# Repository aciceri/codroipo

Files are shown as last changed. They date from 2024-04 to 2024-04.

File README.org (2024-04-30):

* Codroipo

~codroipo~ is my personalized [[https://github.com/beekeeb/Allium58][Allium58]].
Basically I simply removed the OLED display and everything related to wired build, sligthly moved some components and added some cosmetics.

** Build the firmware

#+BEGIN_SRC sh
nix build github:aciceri/codroipo#firmware
#+END_SRC

** Flash the firmware

#+BEGIN_SRC sh
nix run github:aciceri/codroipo#flash
#+END_SRC

** Pictures

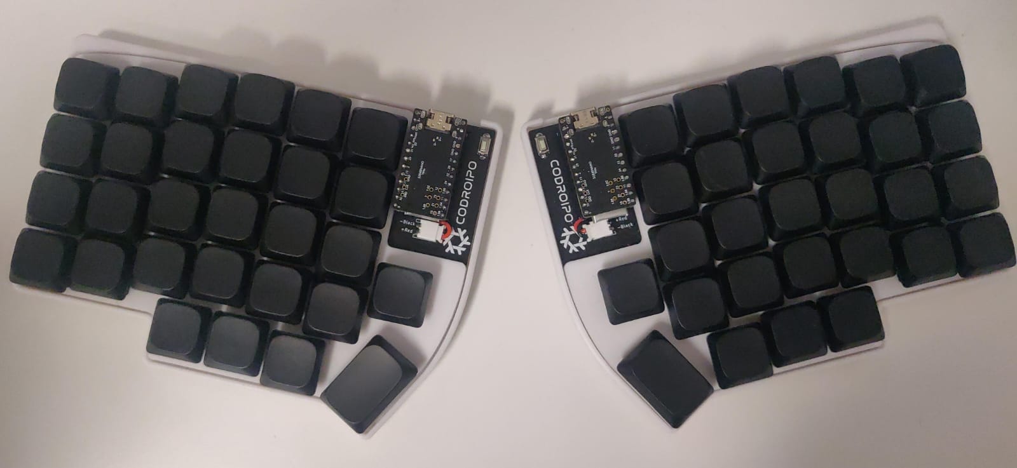
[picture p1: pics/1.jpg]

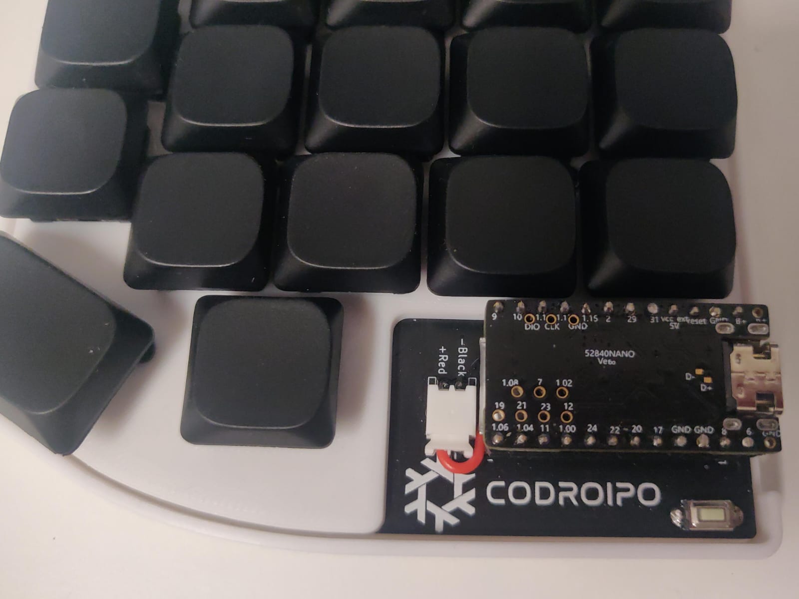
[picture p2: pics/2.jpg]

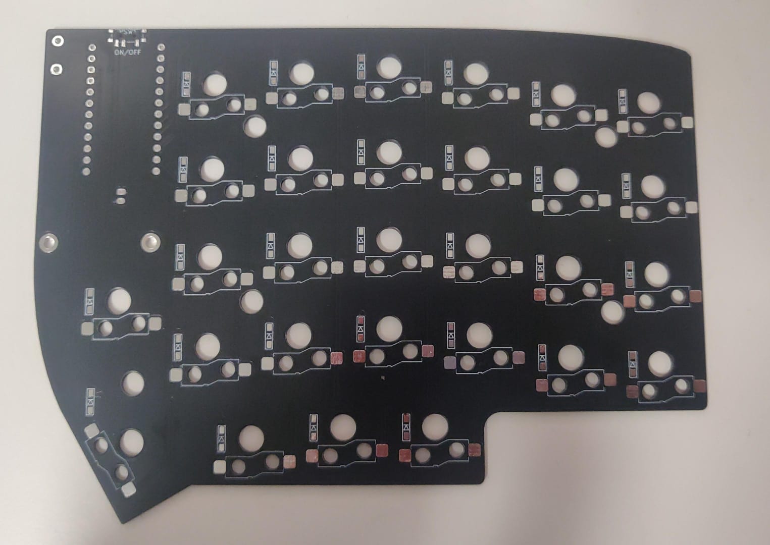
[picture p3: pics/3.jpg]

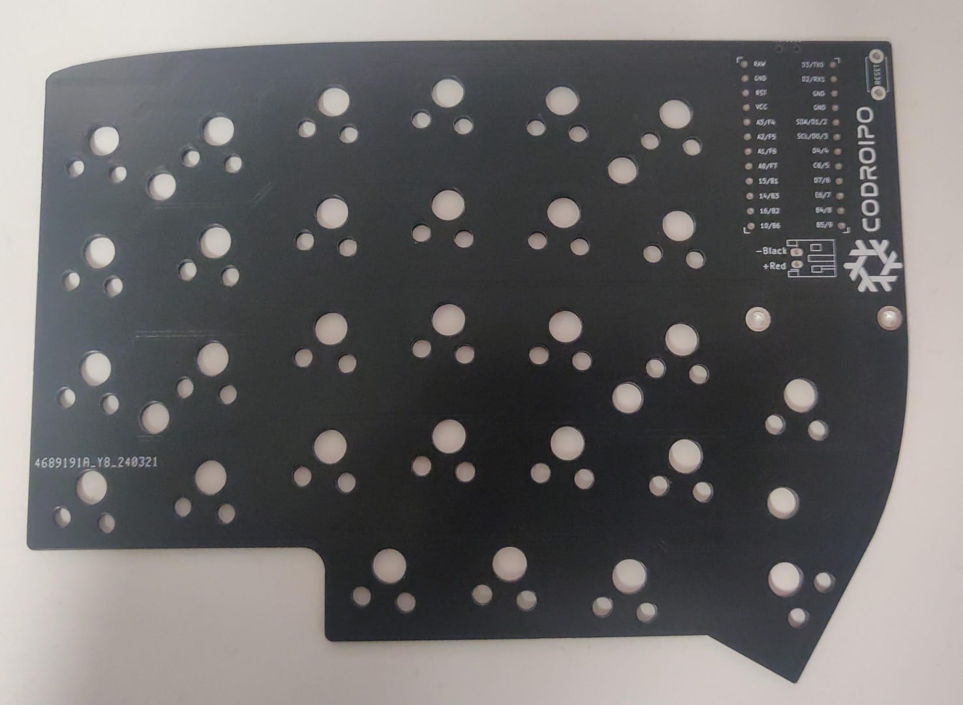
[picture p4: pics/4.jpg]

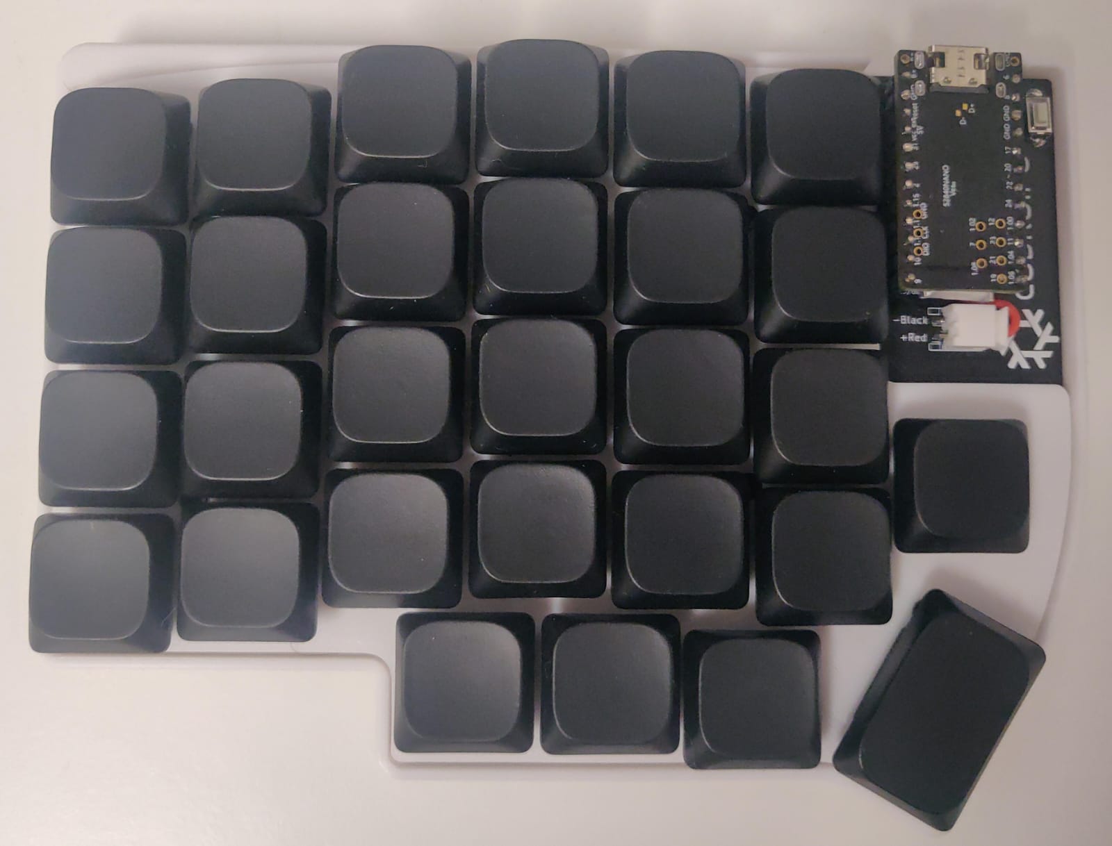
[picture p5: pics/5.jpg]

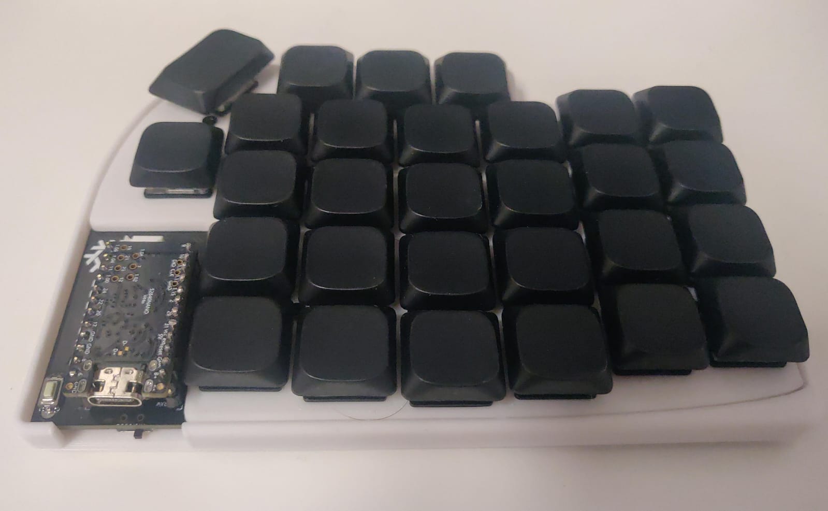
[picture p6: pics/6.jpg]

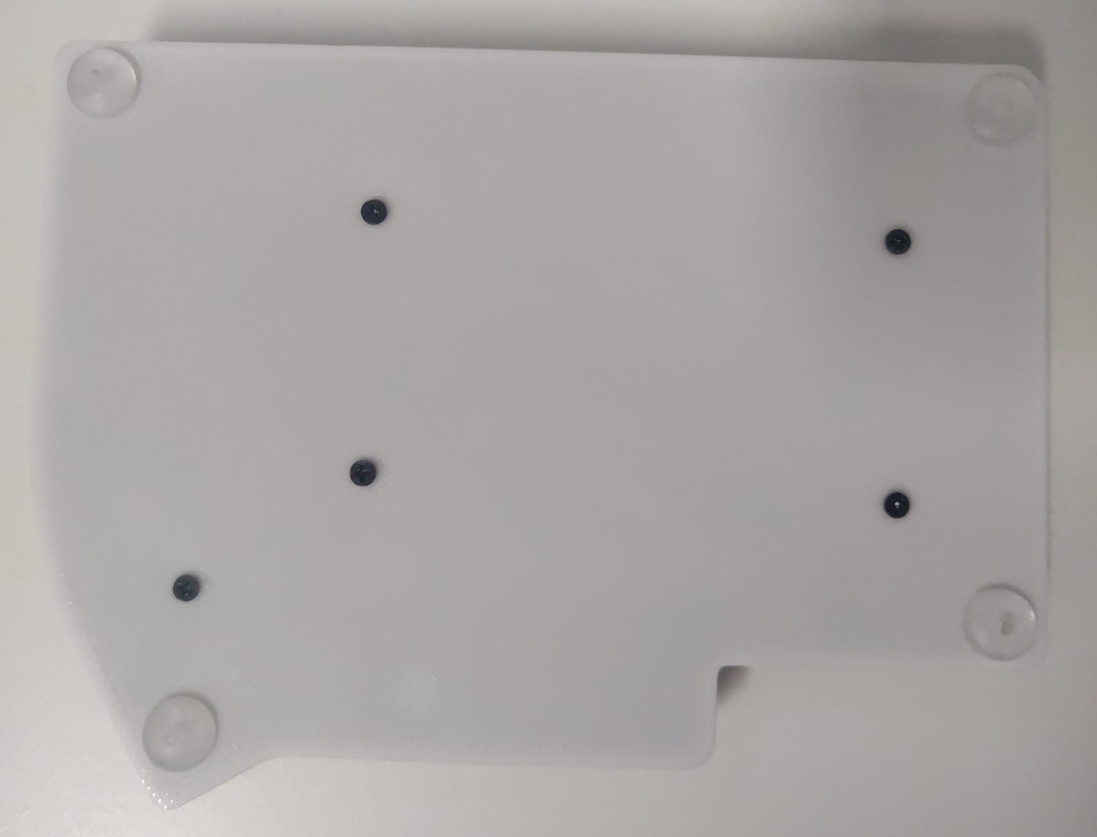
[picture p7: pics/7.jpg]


** Aknowledgements

- [[https://github.com/beekeeb][beekeeb]] for the original [[https://github.com/beekeeb/Allium58][Allium58]]
- [[https://github.com/kata0510][kata0510]] for the original [[https://github.com/kata0510/Lily58][Lily58]] design which the Allium58 is based on
- [[https://github.com/lilyinstarlight][lilyinstarlight]] for [[https://github.com/lilyinstarlight/zmk-nix][zmk-nix]] which allows building [[https://zmk.dev/l][ZMK]] firmware with Nix
- [[https://www.fiverr.com/jorgetukuy][jorgetukuy]] for changing the original Allium58 case according to my specifications

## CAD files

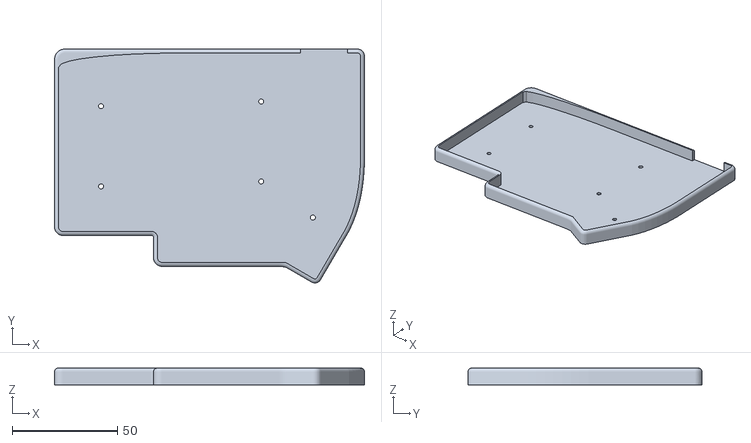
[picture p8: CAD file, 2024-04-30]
case/bottom.stl
147.5 x 111.3 x 8.00

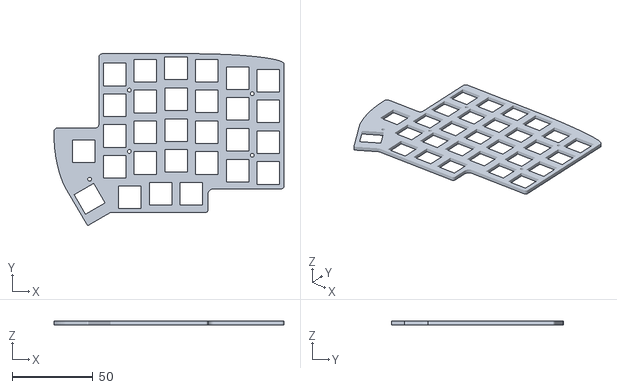
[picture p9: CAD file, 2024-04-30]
case/top.stl
142.5 x 106.3 x 2.50

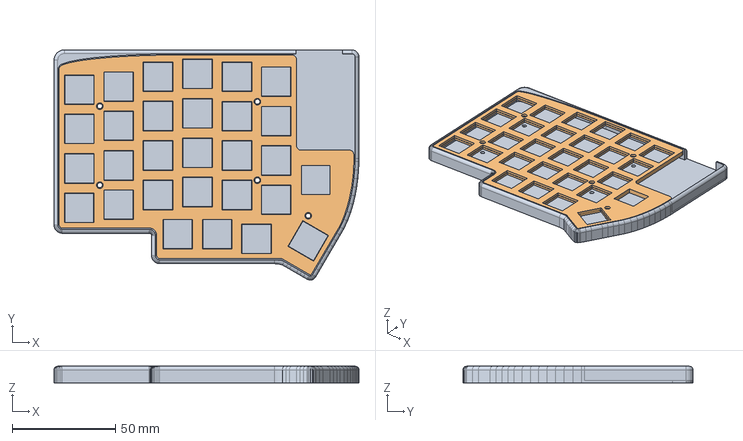
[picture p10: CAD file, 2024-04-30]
case/case.FCStd
147.5 x 111.3 x 8.00 mm
bottom
top

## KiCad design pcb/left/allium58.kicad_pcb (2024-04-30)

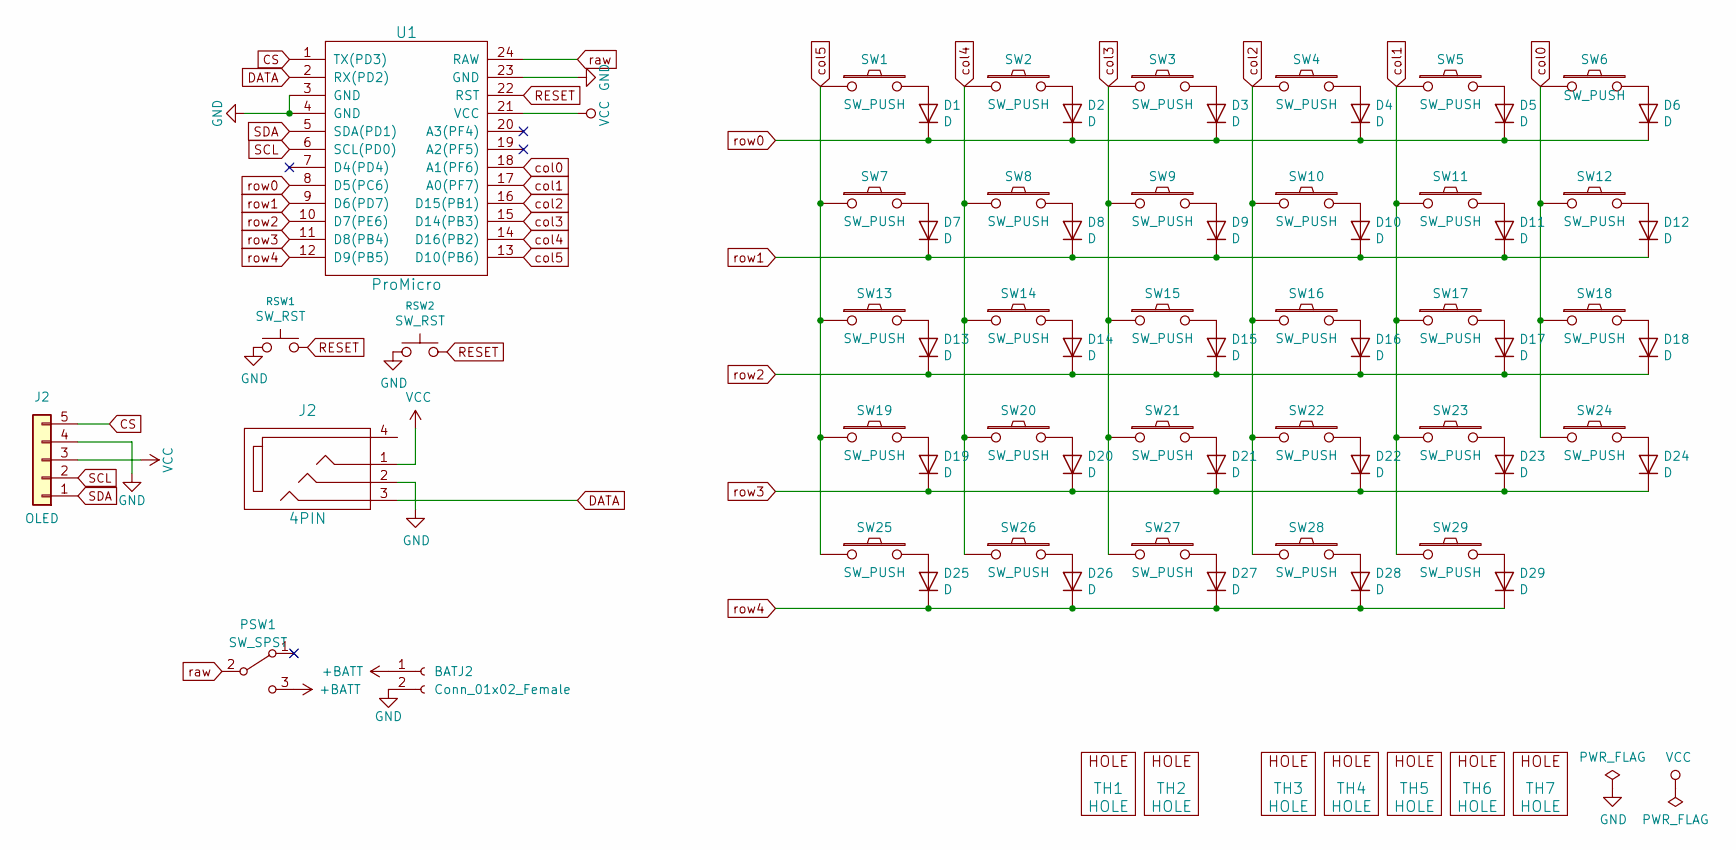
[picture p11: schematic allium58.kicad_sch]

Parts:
BATJ2: Conn_01x02_Female; JST_PH_S2B-PH-K_1x02_P2.00mm_Horizontal
D1, D2, D3, D4, D5, D6, D7, D8, D9, D10, D11, D12, D13, D14, D15, D16, D17, D18, D19, D20, D21, D22, D23, D24, D25, D26, D27, D28, D29: D; Diode_SOD123
J2: 4PIN; MJ-4PP-9
PSW1: SW_SPST; SW_SPDT_PCM12
RSW1: SW_RST; TACT_SWITCH_TVBP06
RSW2: SW_RST; Panasonic_EVQPUL_EVQPUC
SW1, SW2, SW3, SW4, SW5, SW6, SW7, SW8, SW9, SW10, SW11, SW12, SW13, SW14, SW15, SW16, SW17, SW18, SW19, SW20, SW21, SW22, SW23, SW24, SW25, SW26, SW27, SW28, SW29: SW_PUSH; CherryMX_KailhLowProfile_Hotswap
TH1, TH2: HOLE; M2_HOLE_PCB
TH3, TH4, TH5, TH6, TH7: HOLE; HOLE_M2_TH
U1: ProMicro; ProMicro_v3

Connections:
+BATT: PSW1.3 (C); also elsewhere on the board
CS: J2.5, U1.1 (TX(PD3))
DATA: J2.3, U1.2 (RX(PD2))
GND: J2.2, J2.4, RSW1.1, RSW2.1, U1.3 (GND), U1.4 (GND), U1.23 (GND); also elsewhere on the board
unnamed: D1.2 (A), SW1.2
unnamed: D2.2 (A), SW2.2
unnamed: D3.2 (A), SW3.2
unnamed: D4.2 (A), SW4.2
unnamed: D5.2 (A), SW5.2
unnamed: D6.2 (A), SW6.2
unnamed: D7.2 (A), SW7.2
unnamed: D8.2 (A), SW8.2
unnamed: D9.2 (A), SW9.2
unnamed: D10.2 (A), SW10.2
unnamed: D11.2 (A), SW11.2
unnamed: D12.2 (A), SW12.2
unnamed: D13.2 (A), SW13.2
unnamed: D14.2 (A), SW14.2
unnamed: D15.2 (A), SW15.2
unnamed: D16.2 (A), SW16.2
unnamed: D17.2 (A), SW17.2
unnamed: D18.2 (A), SW18.2
unnamed: D19.2 (A), SW19.2
unnamed: D20.2 (A), SW20.2
unnamed: D21.2 (A), SW21.2
unnamed: D22.2 (A), SW22.2
unnamed: D23.2 (A), SW23.2
unnamed: D24.2 (A), SW24.2
unnamed: D25.2 (A), SW25.2
unnamed: D26.2 (A), SW26.2
unnamed: D27.2 (A), SW27.2
unnamed: D28.2 (A), SW28.2
unnamed: D29.2 (A), SW29.2
RESET: RSW1.2, RSW2.2, U1.22 (RST)
SCL: J2.2, U1.6 (SCL(PD0))
SDA: J2.1, U1.5 (SDA(PD1))
VCC: J2.1, J2.3, U1.21 (VCC)
col0: SW6.1, SW12.1, SW18.1, SW24.1, U1.18 (A1(PF6))
col1: SW5.1, SW11.1, SW17.1, SW23.1, SW29.1, U1.17 (A0(PF7))
col2: SW4.1, SW10.1, SW16.1, SW22.1, SW28.1, U1.16 (D15(PB1))
col3: SW3.1, SW9.1, SW15.1, SW21.1, SW27.1, U1.15 (D14(PB3))
col4: SW2.1, SW8.1, SW14.1, SW20.1, SW26.1, U1.14 (D16(PB2))
col5: SW1.1, SW7.1, SW13.1, SW19.1, SW25.1, U1.13 (D10(PB6))
raw: PSW1.2 (B), U1.24 (RAW)
row0: D1.1 (K), D2.1 (K), D3.1 (K), D4.1 (K), D5.1 (K), D6.1 (K), U1.8 (D5(PC6))
row1: D7.1 (K), D8.1 (K), D9.1 (K), D10.1 (K), D11.1 (K), D12.1 (K), U1.9 (D6(PD7))
row2: D13.1 (K), D14.1 (K), D15.1 (K), D16.1 (K), D17.1 (K), D18.1 (K), U1.10 (D7(PE6))
row3: D19.1 (K), D20.1 (K), D21.1 (K), D22.1 (K), D23.1 (K), D24.1 (K), U1.11 (D8(PB4))
row4: D25.1 (K), D26.1 (K), D27.1 (K), D28.1 (K), D29.1 (K), U1.12 (D9(PB5))

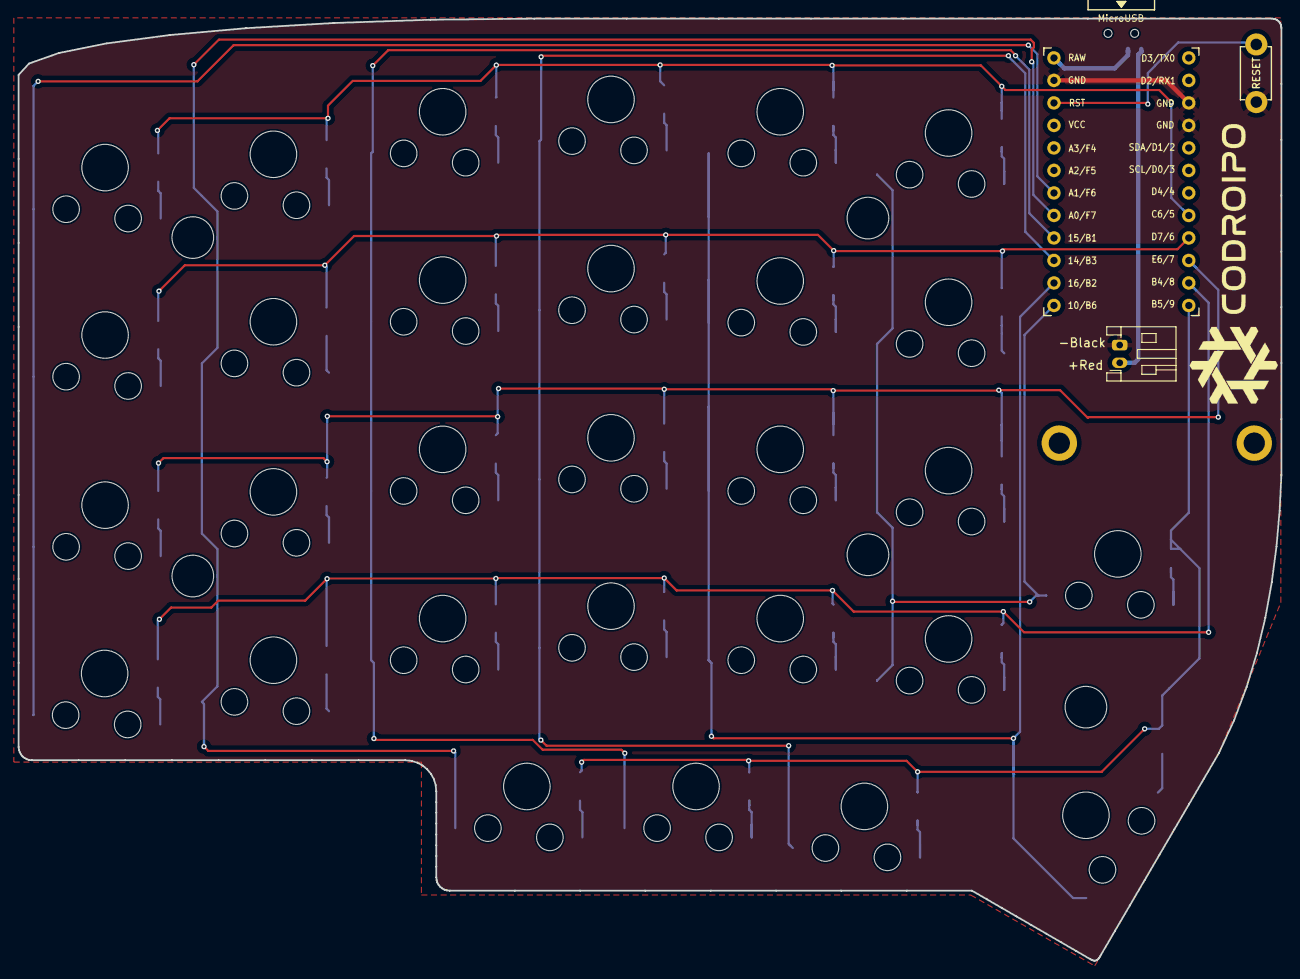
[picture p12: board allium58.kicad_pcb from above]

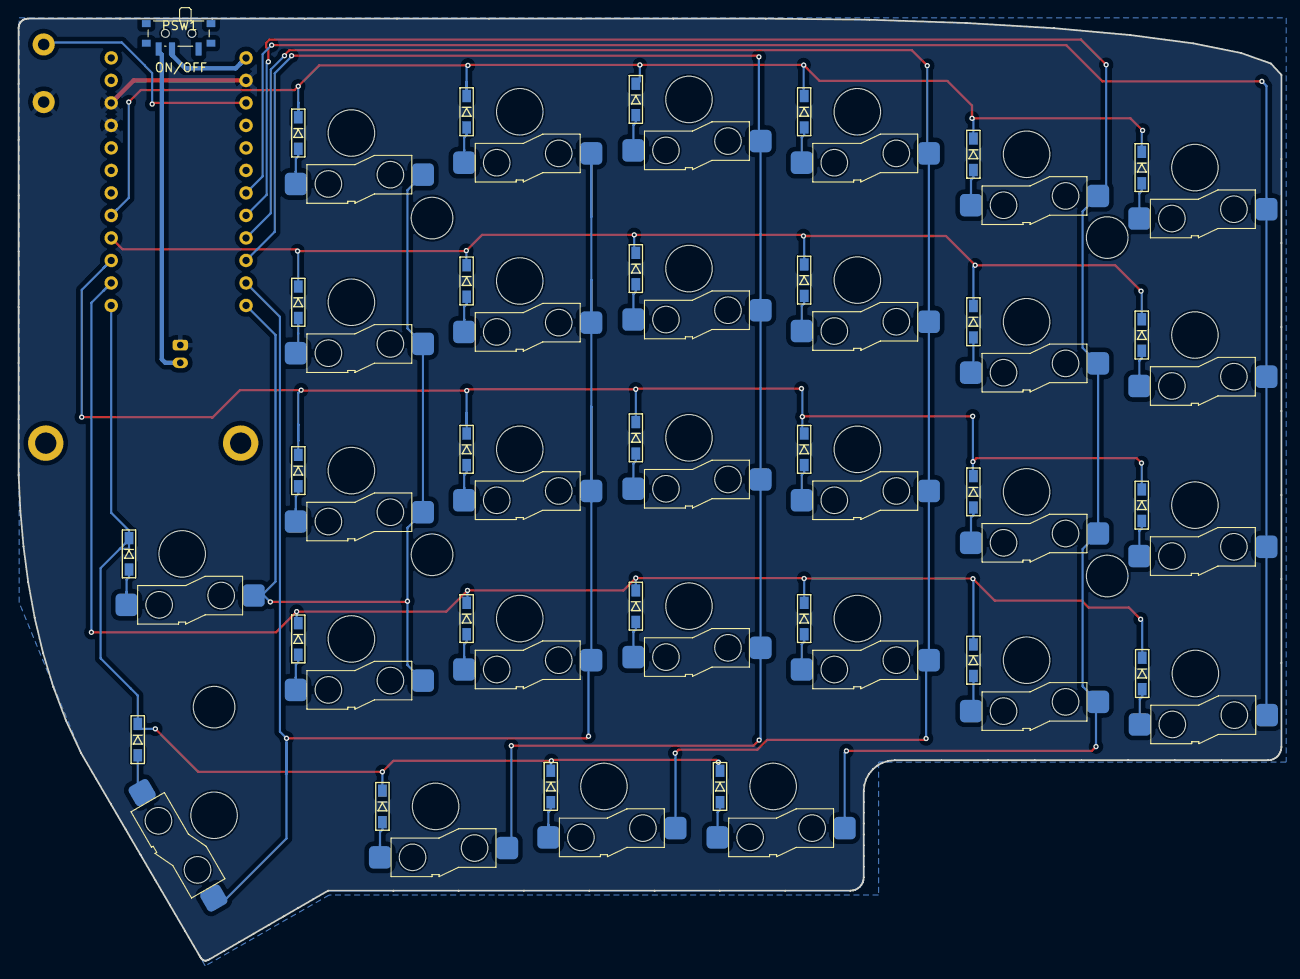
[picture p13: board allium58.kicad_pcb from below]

Board: 2 copper layers, 142.5 x 106.3 mm, 69 parts (37 on the bottom side), 44 nets.

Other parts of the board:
BATJ1: Conn_01x02_Female; JST_PH_S2B-PH-K_1x02_P2.00mm_Horizontal

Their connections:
+BATT: BATJ1.1; also elsewhere on the board
GND: BATJ1.2; also elsewhere on the board
